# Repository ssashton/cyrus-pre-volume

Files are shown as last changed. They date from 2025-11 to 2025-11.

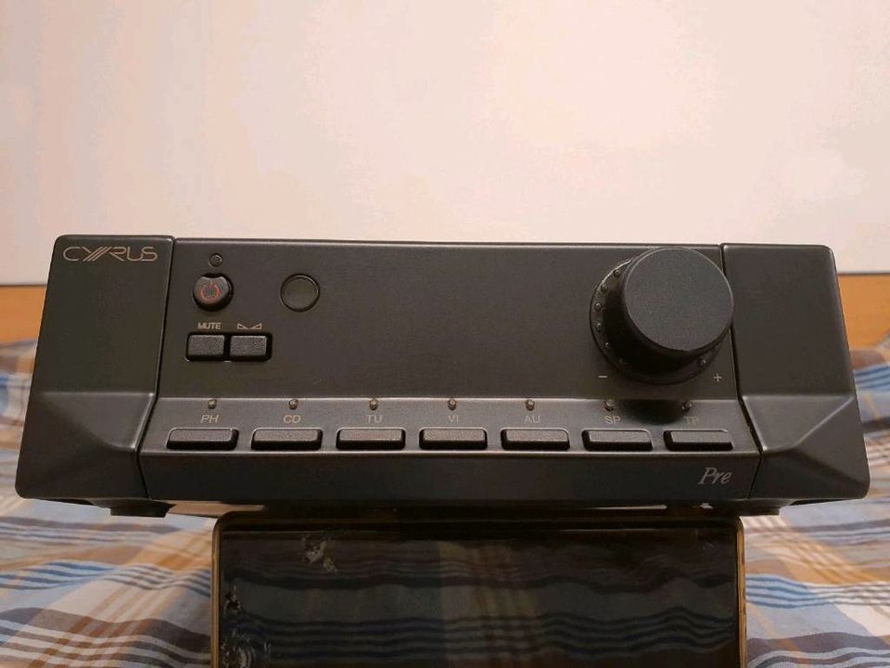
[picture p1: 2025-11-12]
Cyrus Pre Images/00d1c4d2-d2b8-45f6-9919-6ba0c2cf6af5.jpg

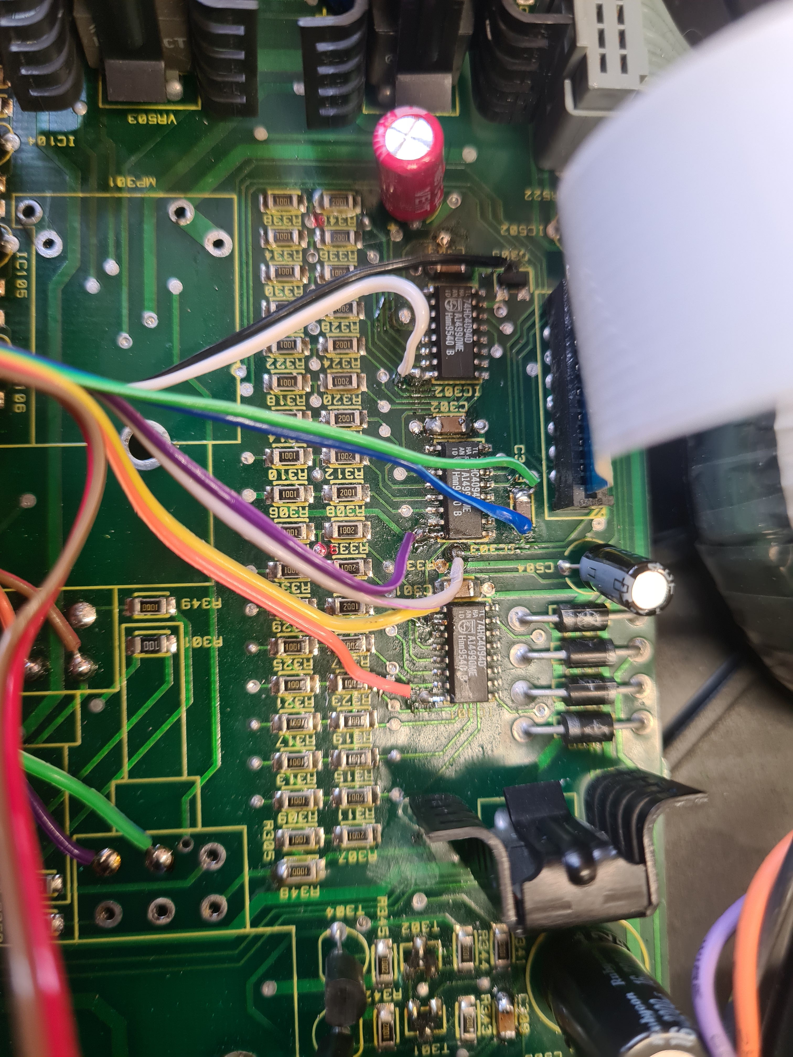
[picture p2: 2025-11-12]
Cyrus Pre Images/20251109_151308.jpg

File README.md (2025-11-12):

# Cyrus Pre Volume Replacement Project

This project provides a modern, drop-in replacement for the **motorised volume potentiometer** used in the original **Cyrus Pre preamplifier**.  
It restores full functionality while eliminating the mechanical failure points of the original design.  
The replacement board reads the original MCU’s control data directly and uses it to drive a **PGA2310 analog volume control IC**, maintaining all original features including balance and mute.

---

## Project Overview

The original Cyrus Pre used a custom motorised potentiometer controlled by a feedback loop.  
In that design, the MCU sent volume data to a stereo R-2R DAC ladder that generated a voltage reference for positioning the pot motor.  
Over time, these potentiometers often fail or become worn beyond the ability of the control loop to function.

This project replaces that system with a **digital control PCB** that intercepts the MCU’s data stream, decodes the requested volume setting, and maps it to **logarithmic dB steps**.  
The decoded levels are then sent to a **PGA2310** dual-channel analog volume IC, chosen for its:

- Direct compatibility with the existing ±15 V rails.
- Low noise and distortion.
- Wide signal level capability (no headroom loss).

Balance and mute commands remain fully functional, preserving the original user experience.

---

## Implementation Notes

- The Cyrus MCU applies per-unit potentiometer calibration, typically only ±1 step.  
  Since the original calibration no longer applies, the firmware snaps all decoded values to the nearest volume step for consistent operation.
- The replacement PCB fits the **original motorised pot mounting points** for simple installation.
- A full installation guide is included.

---

## Repository Contents

### 📂 **Cyrus Pre Volume KiCAD**
- Complete PCB design files and schematics.

### 📂 **Cyrus Pre Volume Code Arduino**
- Firmware that reads the Cyrus MCU’s shift-register data, decodes volume/balance/mute, and controls the PGA2310.

### 📂 **Cyrus Pre Audio Measurements**
- Objective test data verifying performance of the replacement circuit.

### 📂 **Cyrus Pre Images**
- Reference and build photos of the original and replacement assemblies.

### 📄 **Cyrus Pre HA7L Service Manual.pdf**
- Official service documentation for the original preamp.

### 📦 **Cyrus Pre Volume Gerbers.zip**
- Gerber files ready for PCB manufacture.

### 📄 **Cyrus Pre Volume Repair Guide.pdf**
- Installation instructions with images.

### 📄 **Cyrus Pre Volume Replacement Schematic.pdf**
- PDF schematic for the replacement board.

---

## Usage

1. Fabricate the PCB using the provided Gerber files.  
2. Program the microcontroller with the supplied Arduino firmware. (Arduino Pro Micro: Micro-USB, 5V version) 
3. Remove the original potentiometers.
4. Follow the repair guide for wiring.
5. Install the board using the existing motorised pot mounting holes.
6. Confirm operation.

---

## Credits

Project by **Simon Ashton / Tenson on DIYAudio.com**, developed to bring the Cyrus Pre preamplifier back to life with a modern, reliable volume control system.  
Four years sitting dissasembled in my draw — but finally repaired 😎

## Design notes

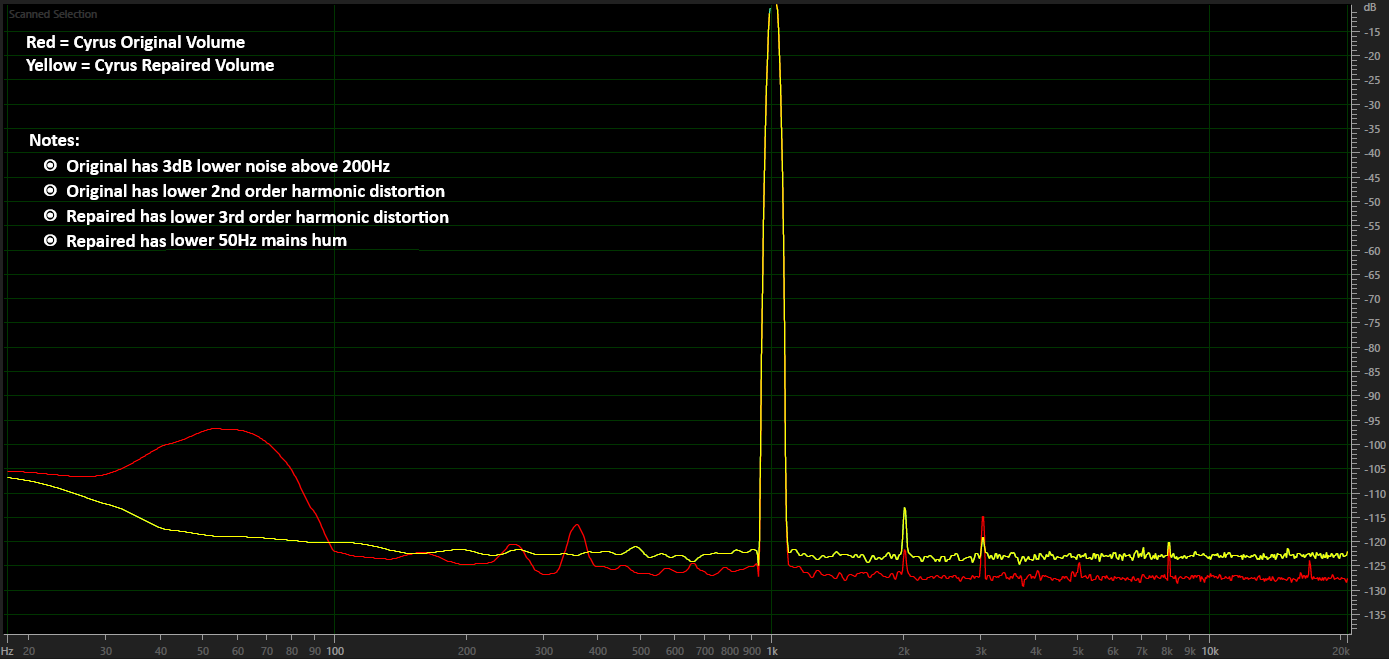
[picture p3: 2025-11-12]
Cyrus Pre Audio Measurments/Cyrus Pre FFT.png

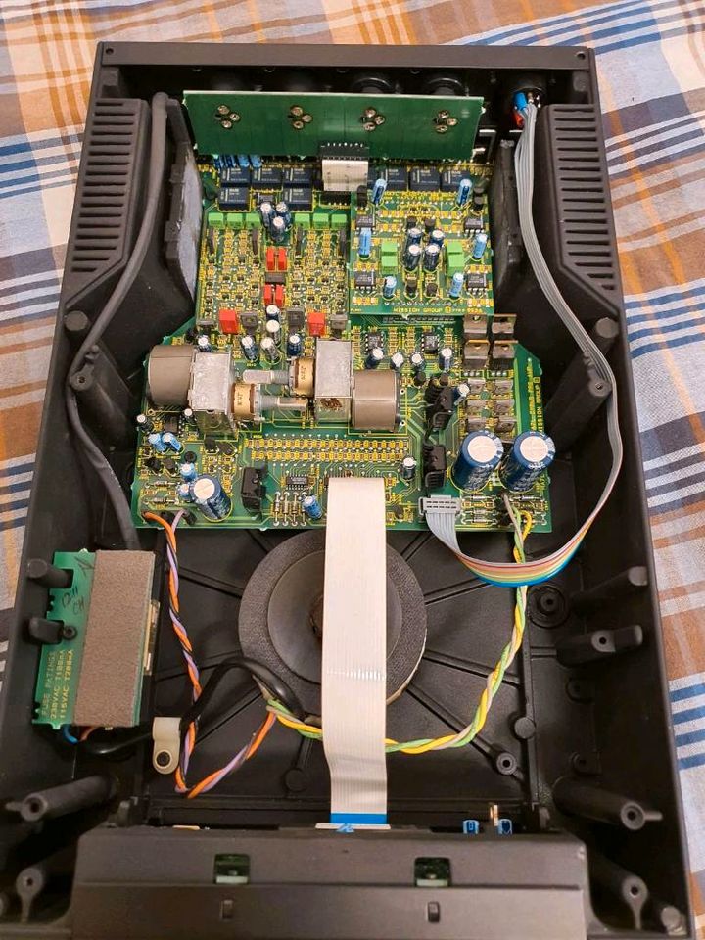
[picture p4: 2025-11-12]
Cyrus Pre Images/56dd4966-28c3-473e-a1d7-f43100ee89ef.jpg

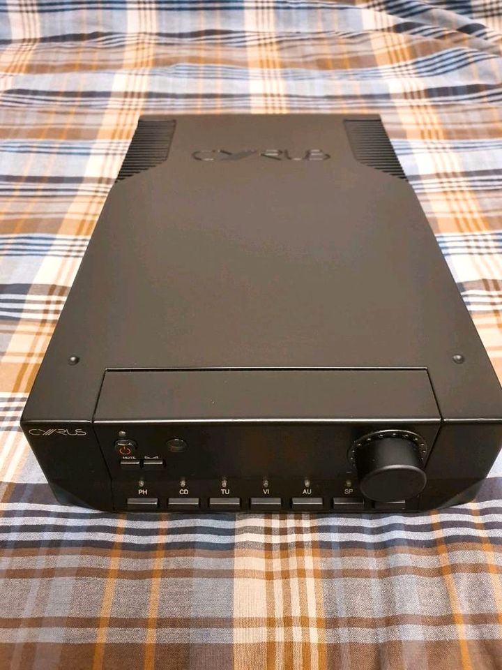
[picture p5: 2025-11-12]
Cyrus Pre Images/75d3d73d-2db0-4df3-9721-dba11c6b0d4e.jpg

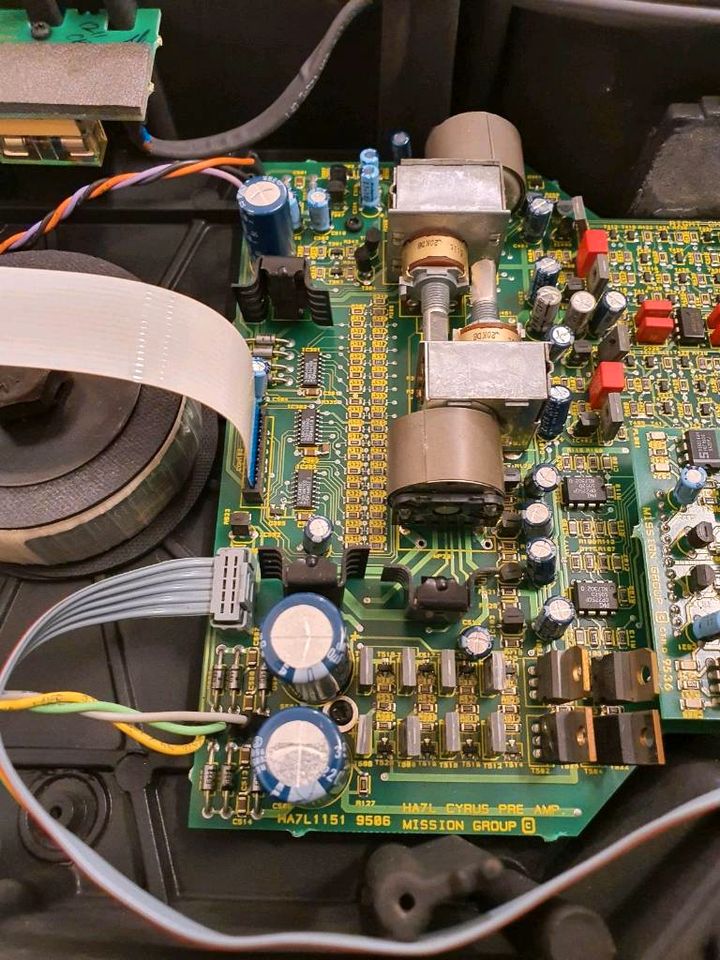
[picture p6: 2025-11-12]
Cyrus Pre Images/8f84e2bc-10a5-4070-b5a5-1acc2a95c4b2.jpg

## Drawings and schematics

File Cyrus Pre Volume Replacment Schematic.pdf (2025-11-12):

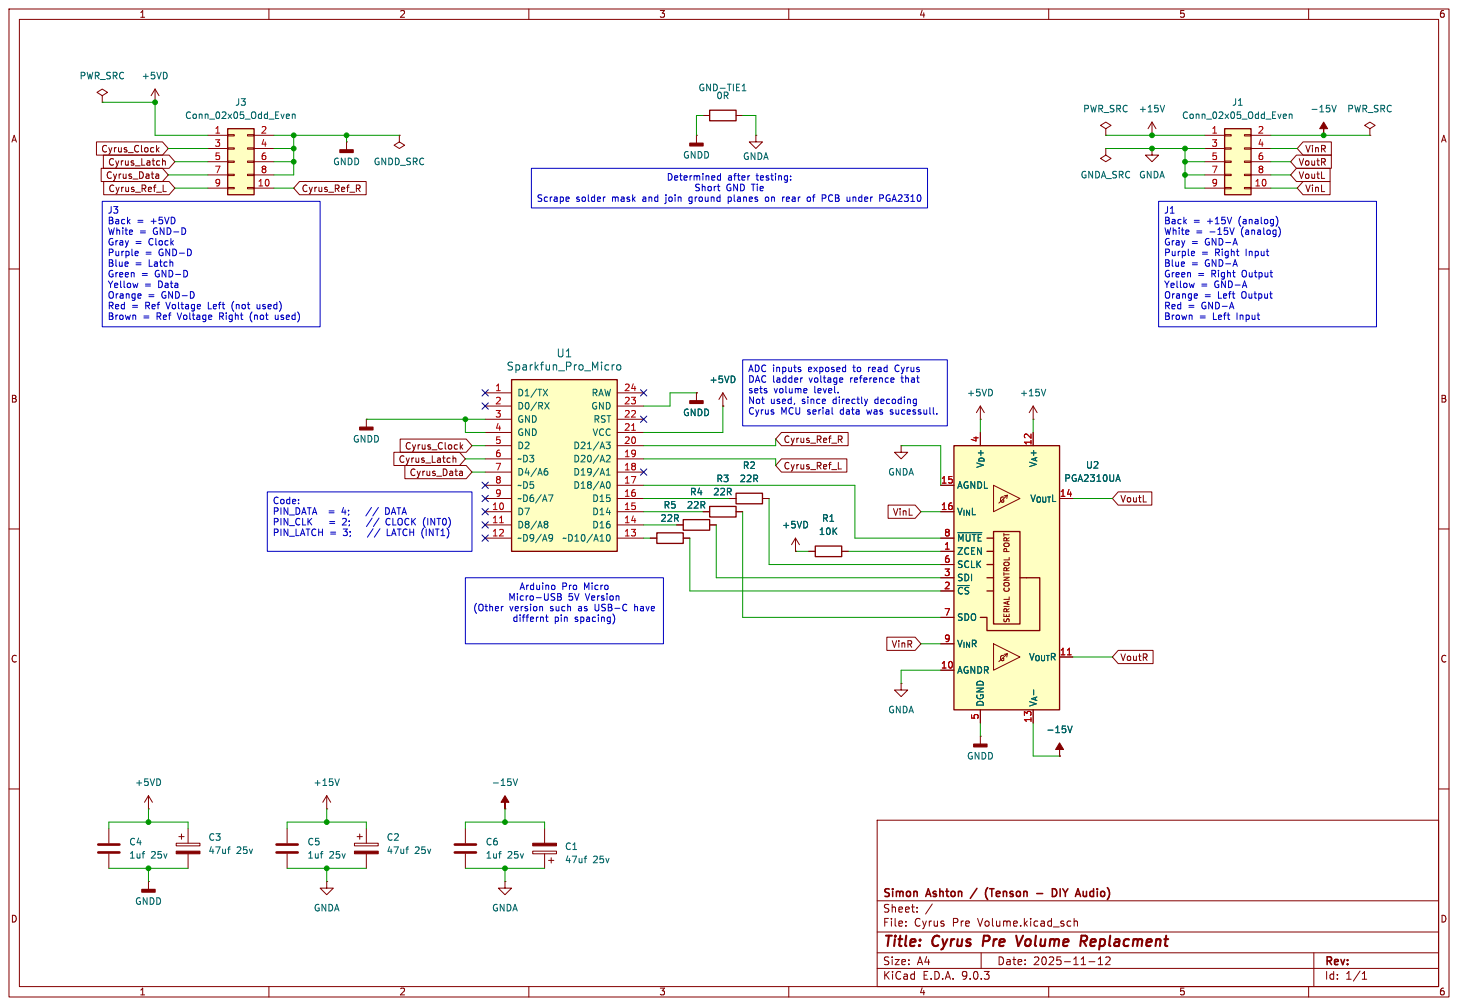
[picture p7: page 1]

J3Back = +5VD White = GND-D Gray = Clock Purple = GND-D

Gray = GND-A
Purple = Right Input Blue = GND-A Green = Right Output Yellow = GND-A Orange = Left Output Red = GND-A

Blue = Latch Green = GND-D

Yellow = Data Orange = GND-D

(Other version such as USB-C have

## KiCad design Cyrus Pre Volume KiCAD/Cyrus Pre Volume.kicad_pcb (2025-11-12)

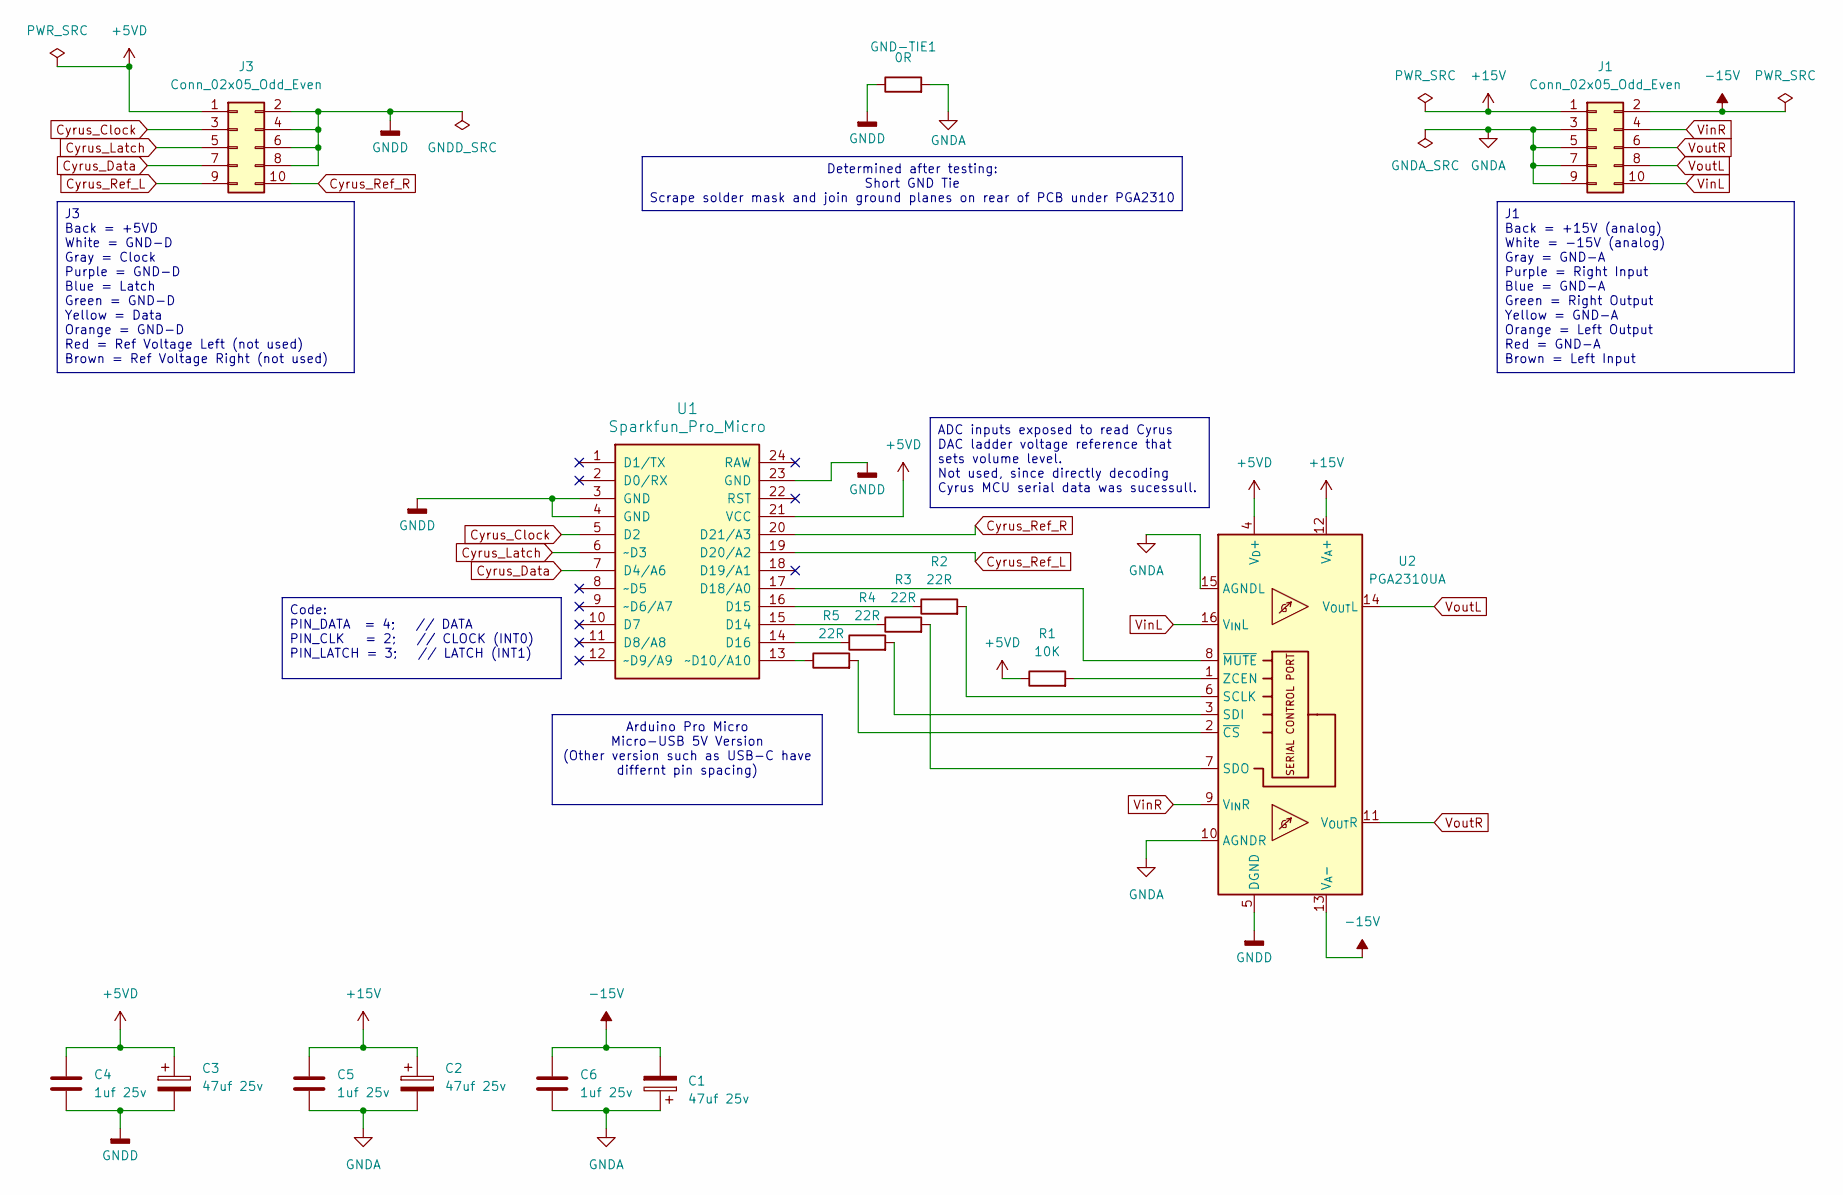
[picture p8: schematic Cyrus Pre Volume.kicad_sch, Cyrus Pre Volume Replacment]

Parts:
C1, C2, C3: 47uf 25v; CP_Radial_Tantal_D6.0mm_P2.50mm
C4, C5, C6: 1uf 25v; C_0603_1608Metric
GND-TIE1: 0R; R_0603_1608Metric
J1, J3: Conn_02x05_Odd_Even; IDC-Header_2x05_P2.54mm_Vertical
R1: 10K; R_0603_1608Metric
R2, R3, R4, R5: 22R; R_0603_1608Metric
U1: Sparkfun_Pro_Micro
U2: PGA2310UA; SOIC-16W_7.5x10.3mm_P1.27mm

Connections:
+5VD: C3.1, C4.1, J3.1, R1.1, U1.21 (VCC), U2.4 (V_{D}+)
+15V: C2.1, C5.1, J1.1, U2.12 (V_{A}+)
-15V: C1.2, C6.1, J1.2, U2.13 (V_{A}-)
Cyrus_Clock: J3.3, U1.5 (D2)
Cyrus_Data: J3.7, U1.7 (D4/A6)
Cyrus_Latch: J3.5, U1.6 (~D3)
Cyrus_Ref_L: J3.9, U1.19 (D20/A2)
Cyrus_Ref_R: J3.10, U1.20 (D21/A3)
GNDA: C1.1, C2.2, C5.2, C6.2, GND-TIE1.2, J1.3, J1.5, J1.7, J1.9, U2.10 (AGNDR), U2.15 (AGNDL)
GNDD: C3.2, C4.2, GND-TIE1.1, J3.2, J3.4, J3.6, J3.8, U1.3 (GND), U1.4 (GND), U1.23 (GND), U2.5 (DGND)
unnamed: R3.1, U1.15 (D14)
unnamed: R2.1, U1.16 (D15)
unnamed: R4.1, U1.14 (D16)
unnamed: U1.17 (D18/A0), U2.8 (~MUTE)
unnamed: R5.1, U1.13 (~D10/A10)
unnamed: R2.2, U2.6 (SCLK)
unnamed: R4.2, U2.3 (SDI)
unnamed: R3.2, U2.7 (SDO)
unnamed: R1.2, U2.1 (ZCEN)
unnamed: R5.2, U2.2 (~CS)
VinL: J1.10, U2.16 (V_{IN}L)
VinR: J1.4, U2.9 (V_{IN}R)
VoutL: J1.8, U2.14 (V_{OUT}L)
VoutR: J1.6, U2.11 (V_{OUT}R)

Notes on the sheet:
ADC inputs exposed to read Cyrus DAC ladder voltage reference that sets volume level. Not used, since directly decoding Cyrus MCU serial data was sucessull.
J1 Back = +15V (analog) White = -15V (analog) Gray = GND-A Purple = Right Input Blue = GND-A Green = Right Output Yellow = GND-A Orange = Left Output Red = GND-A Brown = Left Input
J3 Back = +5VD White = GND-D Gray = Clock Purple = GND-D Blue = Latch Green = GND-D Yellow = Data Orange = GND-D Red = Ref Voltage Left (not used) Brown = Ref Voltage Right (not used)
Arduino Pro Micro Micro-USB 5V Version (Other version such as USB-C have differnt pin spacing)
Determined after testing: Short GND Tie Scrape solder mask and join ground planes on rear of PCB under PGA2310
Code: PIN_DATA = 4; // DATA PIN_CLK = 2; // CLOCK (INT0) PIN_LATCH = 3; // LATCH (INT1)

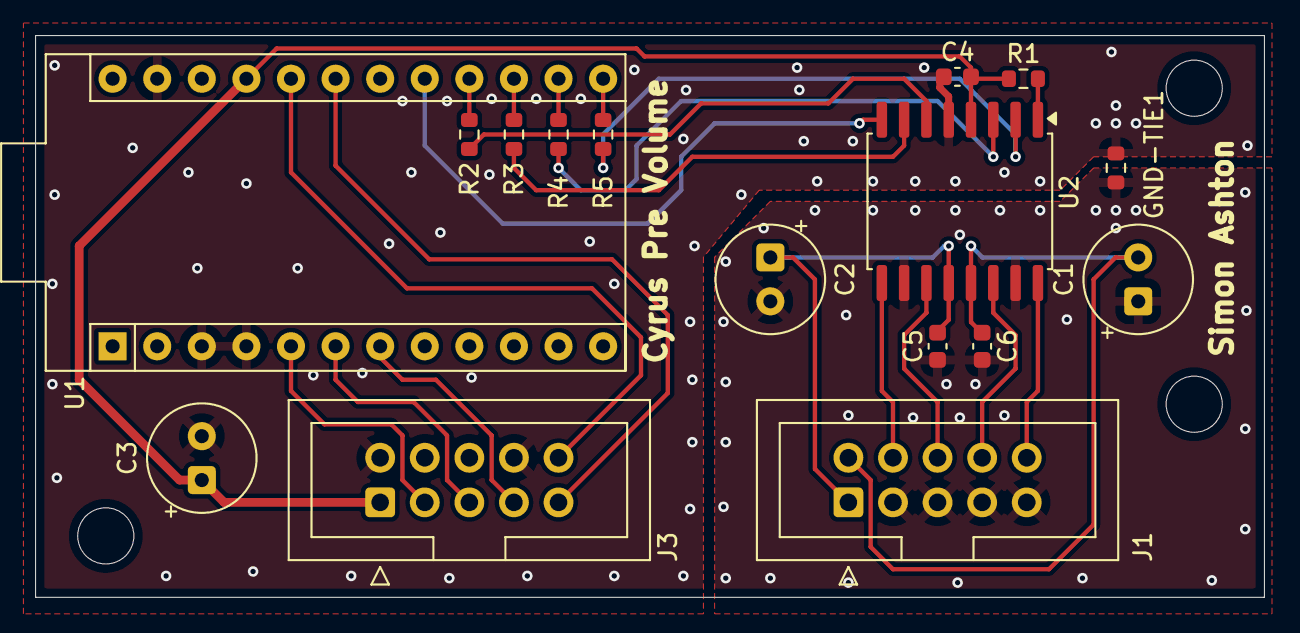
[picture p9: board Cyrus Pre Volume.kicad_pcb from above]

Board: 2 copper layers, 70.0 x 32.0 mm, 16 parts (0 on the bottom side), 24 nets.

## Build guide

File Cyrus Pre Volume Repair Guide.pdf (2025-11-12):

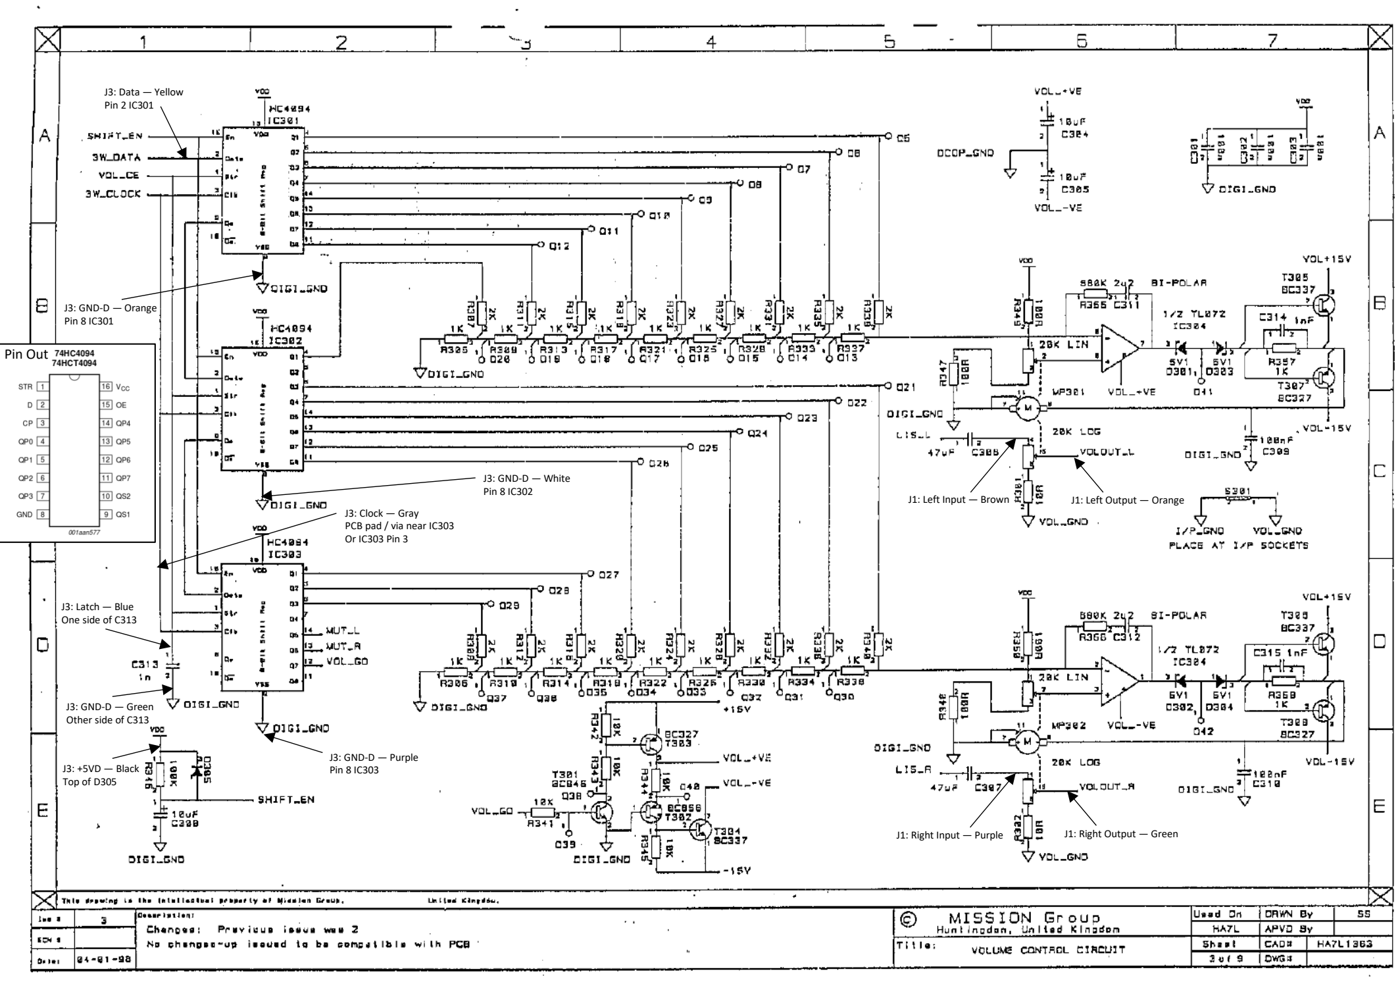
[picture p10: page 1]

J1: Left Input — Brown | J1: Left Output — Orange

J1: Right Output — Green

J3: Data — Yellow
Pin 2 IC301

J1: Right Input — Purple

J3: GND-D — Orange
Pin 8 IC301

## Pin Out

J3: Latch — Blue
One side of C313

J3: GND-D — Green
Other side of C313

J3: Clock — Gray
PCB pad / via near IC303
Or IC303 Pin 3

J3: GND-D — Purple
J3: +5VD — Black | Pin 8 IC303
Top of D305

J3: GND-D — White
Pin 8 IC302

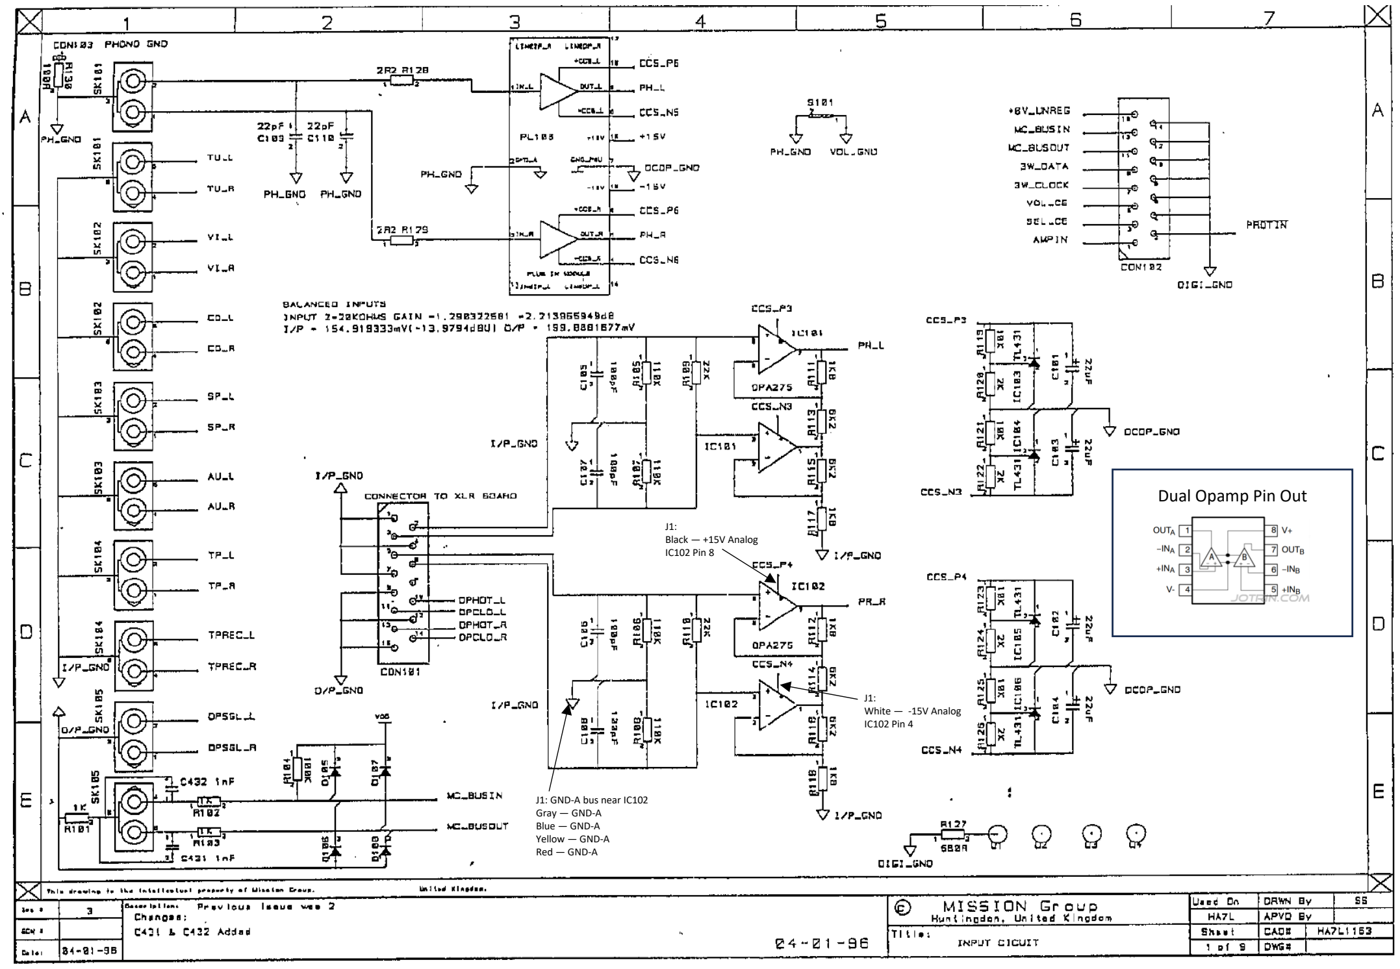
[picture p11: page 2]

J1: GND-A bus near IC102
Gray — GND-A
Blue — GND-A
Yellow — GND-A
Red — GND-A

J1:
Black — +15V Analog
IC102 Pin 8

## Dual Opamp Pin Out

J1:
White — -15V Analog
IC102 Pin 4

# J3 Solder Points

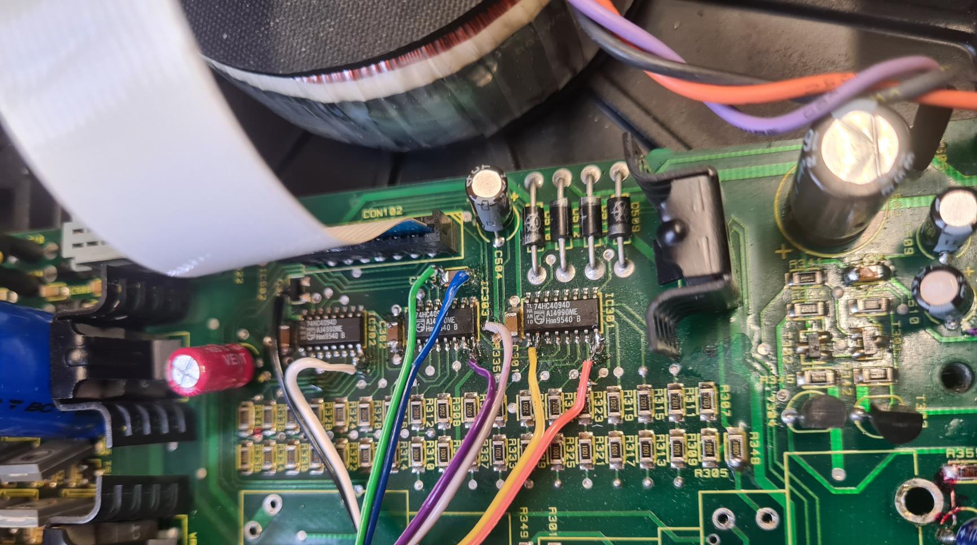
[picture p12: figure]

# J1 Solder Points

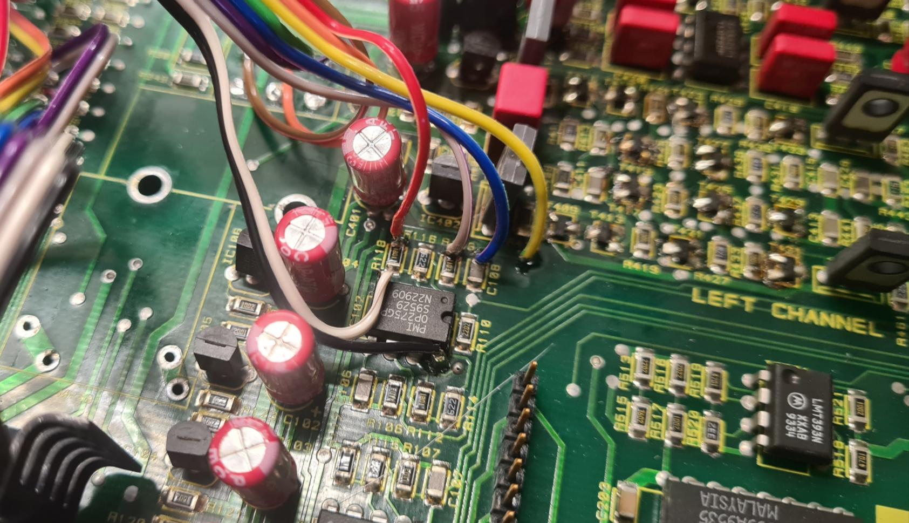
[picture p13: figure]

# J1 Solder Points

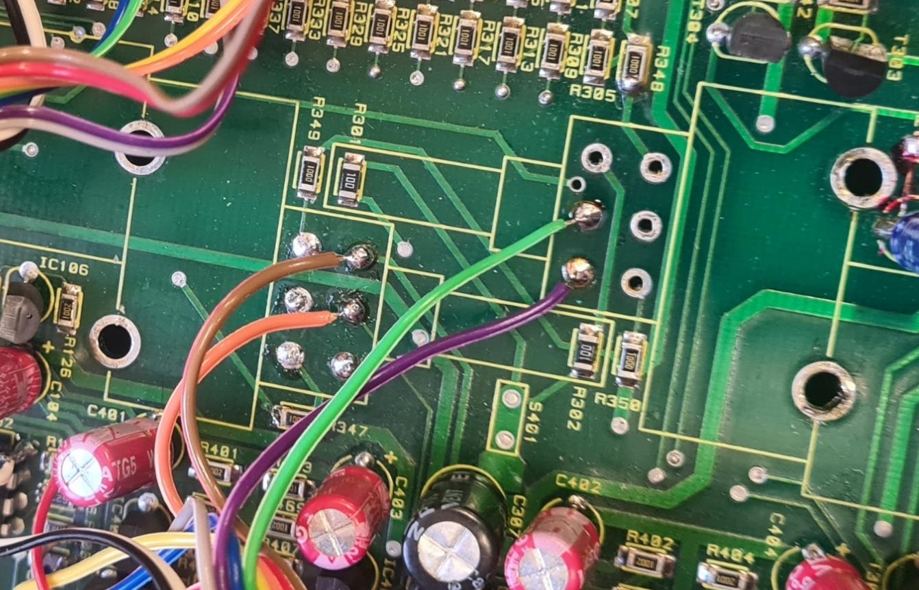
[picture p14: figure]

# Installed

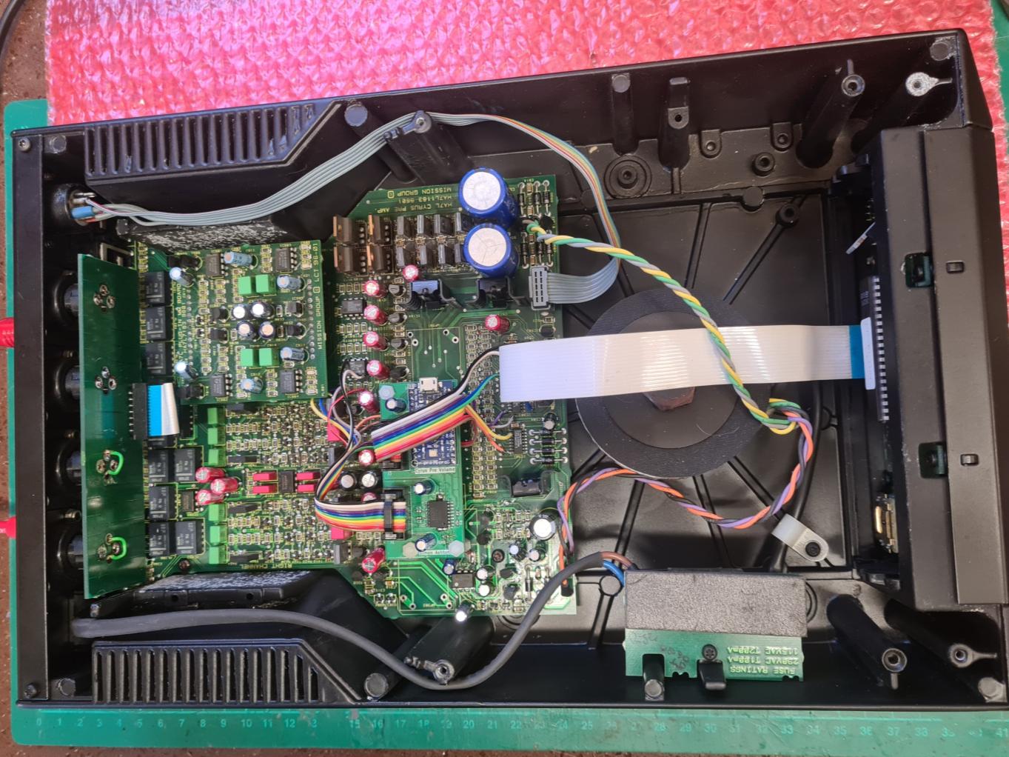
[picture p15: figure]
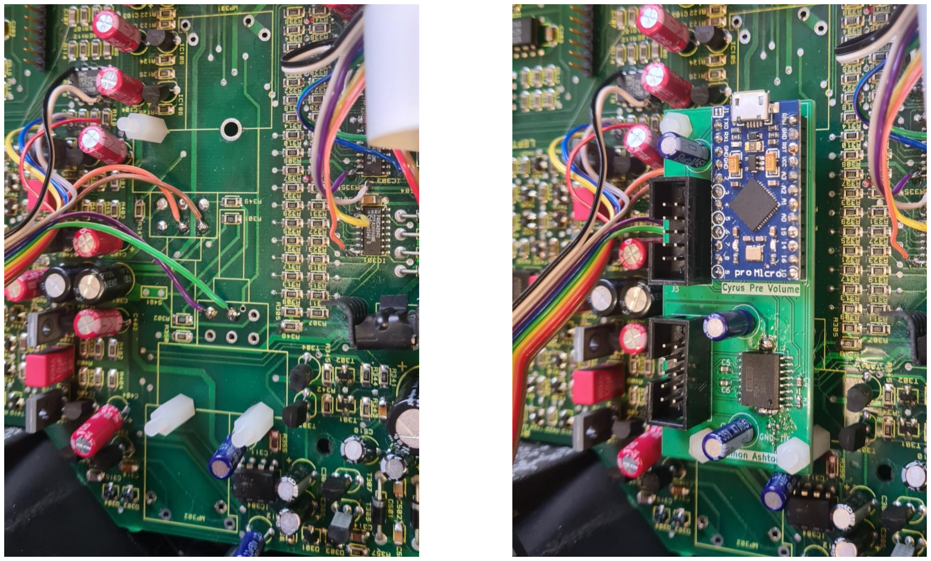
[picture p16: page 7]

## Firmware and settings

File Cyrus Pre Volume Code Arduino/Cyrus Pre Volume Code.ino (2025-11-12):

/* Cyrus_Sniffer_V4_MuteAware_PREREV + PGA2310 SPI (standalone-safe)
 *
 * - Decodes 24-bit word into 2×9-bit DAC ladder values (0..511).  [UNTOUCHED]
 * - Drives a PGA2310 via hardware SPI with correct protocol.       [FIXED]
 * - Standalone safe: does not block waiting for Serial; prints only if Serial present.
 *
 * PGA2310 protocol (correct):
 *   - Send 2 bytes per update: RIGHT first, then LEFT. MSB first.
 *   - SDI latched on rising SCLK → SPI MODE0 (CPOL=0, CPHA=0).
 *   - Code N: 0=mute, 1=−95.5 dB, ..., 192=0 dB, ..., 255=+31.5 dB.
 */

#include <Arduino.h>
#include <math.h>
#include <SPI.h>

// ---------------- USER SETTINGS ----------------
// --- Cyrus digital interface (input from shift register) ---
const uint8_t PIN_DATA  = 4;   // DATA from Cyrus (serial data)
const uint8_t PIN_CLK   = 2;   // CLOCK (INT0)
const uint8_t PIN_LATCH = 3;   // LATCH (INT1)

// --- PGA2310 SPI interface (output to volume IC) ---
const uint8_t PIN_PGA_CS   = 10;  // Chip Select (active LOW)
const uint8_t PIN_PGA_SCLK = 15;  // SPI SCK (hardware SPI on Micro)
const uint8_t PIN_PGA_SDI  = 16;  // SPI MOSI (hardware SPI on Micro)
const uint8_t PIN_PGA_SDO  = 14;  // SPI MISO (from PGA) — connected but unused
const uint8_t PIN_PGA_MUTE = A0;  // Hardware MUTE pin — we force HIGH in setup and never touch again
// ZCEN is tied HIGH via 10k (always enabled)

// --- SPI setup parameters ---
const uint32_t PGA_SPI_CLOCK_HZ = 1000000UL; // 1 MHz is plenty
const uint8_t  PGA_SPI_MODE     = SPI_MODE0; // CPOL=0, CPHA=0 (PGA2310 latches on rising edge)

// --- Mapping / decode options (baseline) ---
const uint8_t  LEFT_SHIFT  = 0;     // LEFT = b8..b0
const uint8_t  RIGHT_SHIFT = 10;    // RIGHT = b18..b10
const uint16_t FIELD_MASK  = 0x1FF; // 9 bits

const bool ACTIVE_LOW = true;   // ladder active-low → invert bits
const bool REVERSE9   = true;   // fields arrive MSB→LSB → reverse
bool FLIP_POSITION    = true;   // big value = mute, small = loud → flip so 0..511 = quiet..loud

volatile int DIFF_THRESHOLD_COUNTS = 5; // ignore tiny L/R diffs (unless mute on either side)

float ALPHA     = 0.20f;    // your current feel
float ATTEN_MIN = -135.0f;  // your current bottom stop (clipped to PGA range later)
// ------------------------------------------------

// Capture state
volatile uint32_t shiftReg = 0;
volatile uint16_t edgeCount = 0;
volatile bool wordReady = false;
volatile uint32_t capturedW24 = 0;
volatile uint16_t capturedEdges = 0;

// -------- Helpers --------
static inline uint16_t bitrev9(uint16_t x) {
  uint16_t r = 0;
  for (uint8_t i = 0; i < 9; ++i) r |= ((x >> i) & 0x1) << (8 - i);
  return r & 0x1FF;
}

// Extract and apply transforms to get a natural 0..511 "position" (increasing with volume)
static inline uint16_t fieldDecoded(uint32_t w24, uint8_t start) {
  uint16_t v = (w24 >> start) & FIELD_MASK; // raw
  if (ACTIVE_LOW) v = (~v) & FIELD_MASK;    // active-low → natural
  if (REVERSE9)   v = bitrev9(v);           // MSB→LSB → LSB→MSB
  if (FLIP_POSITION) v = 511 - v;           // big=quiet → small=quiet
  return v; // 0..511 (0 = lowest volume)
}

// Continuous dB mapping (no hardware mute handling here)
float posToDB(uint16_t code) {
  float p = (float)code / 511.0f;   // 0..1 (quiet..loud)
  float shaped = powf(p, ALPHA);    // log-like feel
  float dB = ATTEN_MIN * (1.0f - shaped);
  return dB;
}

// Clip and snap to PGA2310 0.5 dB step
float snapToPGA(float dB) {
  if (dB < -95.5f) dB = -95.5f;
  if (dB > 0.0f)   dB = 0.0f;
  return round(dB / 0.5f) * 0.5f;
}

// ---- PGA2310: Convert snapped dB to device code N ----
// N mapping: 0=mute, 1=−95.5 dB, ..., 192=0 dB, ..., 255=+31.5 dB.
static inline uint8_t dB_to_pga_code(float dB_snapped) {
  if (dB_snapped > 0.0f)   dB_snapped = 0.0f;
  if (dB_snapped < -95.5f) dB_snapped = -95.5f;
  float Nf = 255.0f - 2.0f * (31.5f - dB_snapped); // 0 dB -> 192
  int   N  = (int)lroundf(Nf);
  if (N < 1)   N = 1;     // -95.5 dB
  if (N > 255) N = 255;   // +31.5 dB
  return (uint8_t)N;
}

// Drive PGA2310: two bytes per update (RIGHT then LEFT), MSB-first
static inline void pga_send(uint8_t left_code, uint8_t right_code) {
  digitalWrite(PIN_PGA_CS, LOW);
  // RIGHT first, then LEFT as per PGA2310 framing
  SPI.transfer(right_code);
  SPI.transfer(left_code);
  digitalWrite(PIN_PGA_CS, HIGH);
}

// -------- ISRs --------
void onClockEdge() {
  uint8_t bit = (uint8_t)(digitalRead(PIN_DATA) & 1);
  shiftReg = ((shiftReg << 1) | bit) & 0xFFFFFFUL;  // keep 24 LSBs
  edgeCount++;
}

void onLatchRise() {
  capturedW24   = shiftReg & 0xFFFFFFUL;
  capturedEdges = edgeCount;
  edgeCount     = 0;
  wordReady     = true;
}

// -------- Arduino --------
void setup() {
  // --- Critical pin init BEFORE any Serial wait ---
  pinMode(PIN_PGA_CS,   OUTPUT);
  pinMode(PIN_PGA_MUTE, OUTPUT);
  digitalWrite(PIN_PGA_CS, HIGH);   // idle high
  digitalWrite(PIN_PGA_MUTE, HIGH); // force unmuted (active-low pin)

  // Keep 32U4 in SPI master mode regardless of external 5V / no-USB
  pinMode(SS, OUTPUT);
  digitalWrite(SS, HIGH);

  // Bring up Serial but DO NOT wait for it (standalone-safe)
  Serial.begin(115200);

  // Cyrus inputs and interrupts
  pinMode(PIN_DATA,  INPUT_PULLUP);
  pinMode(PIN_CLK,   INPUT_PULLUP);
  pinMode(PIN_LATCH, INPUT_PULLUP);

  attachInterrupt(digitalPinToInterrupt(PIN_CLK),   onClockEdge, FALLING);
  attachInterrupt(digitalPinToInterrupt(PIN_LATCH), onLatchRise, RISING);

  // SPI init (hardware SPI on Micro: SCK=D15, MOSI=D16, MISO=D14)
  SPI.begin();

  if (Serial) {
    Serial.println(F("Cyrus 24-bit sniffer (ATmega32U4) + PGA2310 SPI (standalone-safe)"));
    Serial.println(F("Fields: LEFT b8..b0, RIGHT b18..b10, spacer b9"));
    Serial.print (F("DIFF_THRESHOLD_COUNTS=")); Serial.println(DIFF_THRESHOLD_COUNTS);
    Serial.print (F("ACTIVE_LOW=")); Serial.print(ACTIVE_LOW);
    Serial.print (F(" REVERSE9=")); Serial.print(REVERSE9);
    Serial.print (F(" FLIP_POSITION=")); Serial.println(FLIP_POSITION);
    Serial.print (F("ALPHA=")); Serial.print(ALPHA, 2);
    Serial.print (F(" ATTEN_MIN=")); Serial.print(ATTEN_MIN, 1);
    Serial.println(F(" dB (for non-mute codes)"));
    Serial.println(F("Mute rule: DECODED field == 0 → send −95.5 dB (no HW mute pin)"));
    Serial.println(F("PGA2310: RIGHT then LEFT, MODE0, 0 dB→N=192, step=0.5 dB, −95.5 dB→N=1, N=0=mute"));
    Serial.println();
  }
}

void loop() {
  if (!wordReady) return;

  noInterrupts();
  uint32_t w24   = capturedW24;
  uint16_t edges = capturedEdges;
  wordReady = false;
  interrupts();

  // --- Decoding path (UNCHANGED) ---
  uint16_t L_pos = fieldDecoded(w24, LEFT_SHIFT);
  uint16_t R_pos = fieldDecoded(w24, RIGHT_SHIFT);

  bool L_is_mute = (L_pos == 0);
  bool R_is_mute = (R_pos == 0);

  if (!L_is_mute && !R_is_mute && abs((int)L_pos - (int)R_pos) < DIFF_THRESHOLD_COUNTS) {
    uint16_t avg = (L_pos + R_pos) / 2;
    L_pos = R_pos = avg;
  }

  float L_dB = L_is_mute ? -95.5f : posToDB(L_pos);
  float R_dB = R_is_mute ? -95.5f : posToDB(R_pos);

  float L_dB_pga = snapToPGA(L_dB);
  float R_dB_pga = snapToPGA(R_dB);

  uint8_t L_code = dB_to_pga_code(L_dB_pga);
  uint8_t R_code = dB_to_pga_code(R_dB_pga);

  // --- PGA2310 write ---
  static uint8_t prev_L_code = 255, prev_R_code = 255; // invalid to force first update
  if (L_code != prev_L_code || R_code != prev_R_code) {
    SPI.beginTransaction(SPISettings(PGA_SPI_CLOCK_HZ, MSBFIRST, PGA_SPI_MODE));
    pga_send(L_code, R_code);  // function sends RIGHT then LEFT
    SPI.endTransaction();
    prev_L_code = L_code;
    prev_R_code = R_code;
  }

  // ---- Serial printout (only if a host is connected) ----
  if (Serial) {
    char hexbuf[7]; snprintf(hexbuf, sizeof(hexbuf), "%06lX", (unsigned long)(w24 & 0xFFFFFFUL));

    Serial.print(F("w24=0x")); Serial.print(hexbuf);
    Serial.print(F("  L="));    Serial.print(L_pos);
    Serial.print(F("  R="));    Serial.print(R_pos);
    Serial.print(F("  edges="));Serial.print(edges);
    if (L_is_mute) Serial.print(F("  L_MUTE"));
    if (R_is_mute) Serial.print(F("  R_MUTE"));
    Serial.print(F("  L_dB="));      Serial.print(L_dB, 1);
    Serial.print(F("  R_dB="));      Serial.print(R_dB, 1);
    Serial.print(F("  L_dB_PGA="));  Serial.print(L_dB_pga, 1);
    Serial.print(F("  R_dB_PGA="));  Serial.print(R_dB_pga, 1);
    Serial.print(F("  L_CODE(N)=")); Serial.print(L_code);
    Serial.print(F("  R_CODE(N)=")); Serial.print(R_code);
    Serial.println();
  }
}
